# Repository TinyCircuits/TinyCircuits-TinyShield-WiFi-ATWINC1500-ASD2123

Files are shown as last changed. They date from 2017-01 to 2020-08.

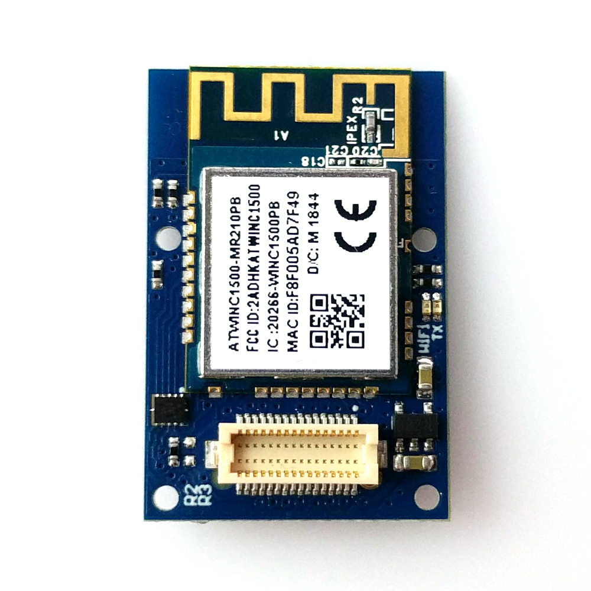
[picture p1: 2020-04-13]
images/ASD2123-R-Tutorial-Image-01.jpg

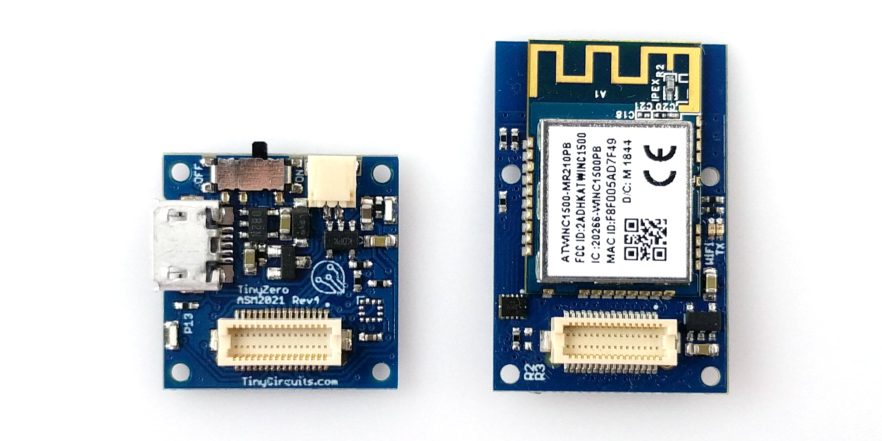
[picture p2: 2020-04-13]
images/ASD2123-R-Tutorial-Image-02.jpg

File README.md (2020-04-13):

# TinyCircuits TinyShield WiFi ATWINC1500 Board
# ASD2123 Rev1

These are the design files for the TinyCircuits ASD2123 Rev 1 PCB.  This is a TinyShield board that has a Atmel ATWINC1500 WiFi module, local power supply and level shifters to connect between the TinyDuino and the WiFi Module. 

Format is in Cadsoft Eagle format - Eagle version 6.2 was used for the original design.

For more infomation on this, check out the product page at TinyCircuits.com:  https://tinycircuits.com/products/wifi-tinyshield-atwinc1500

# License:

Design by TinyCircuits.
All design files are released under the Creative Commons Attribution Share-Alike 3.0 License, see the following link for details: http://creativecommons.org/licenses/by-sa/3.0

All text above must be included in any redistribution or derived design

This project uses designs and concepts developed as part of the Arduino project and the LilyPad project.  The TinyCircuits design files themselves (schematics, PCB and libraries) are not directly derived from these works' design files and have been created new, however the concepts and basic architecture behind the TinyDuino and TinyLily products are derived and we thank the hard work of the organizations below for their contributions to open-source hardware:
  
Original Arduino Uno Design by Team Arduino

LilyPad Arduino Design by Leah Buechley and Sparkfun Electronics

Please support the open-source hardware community

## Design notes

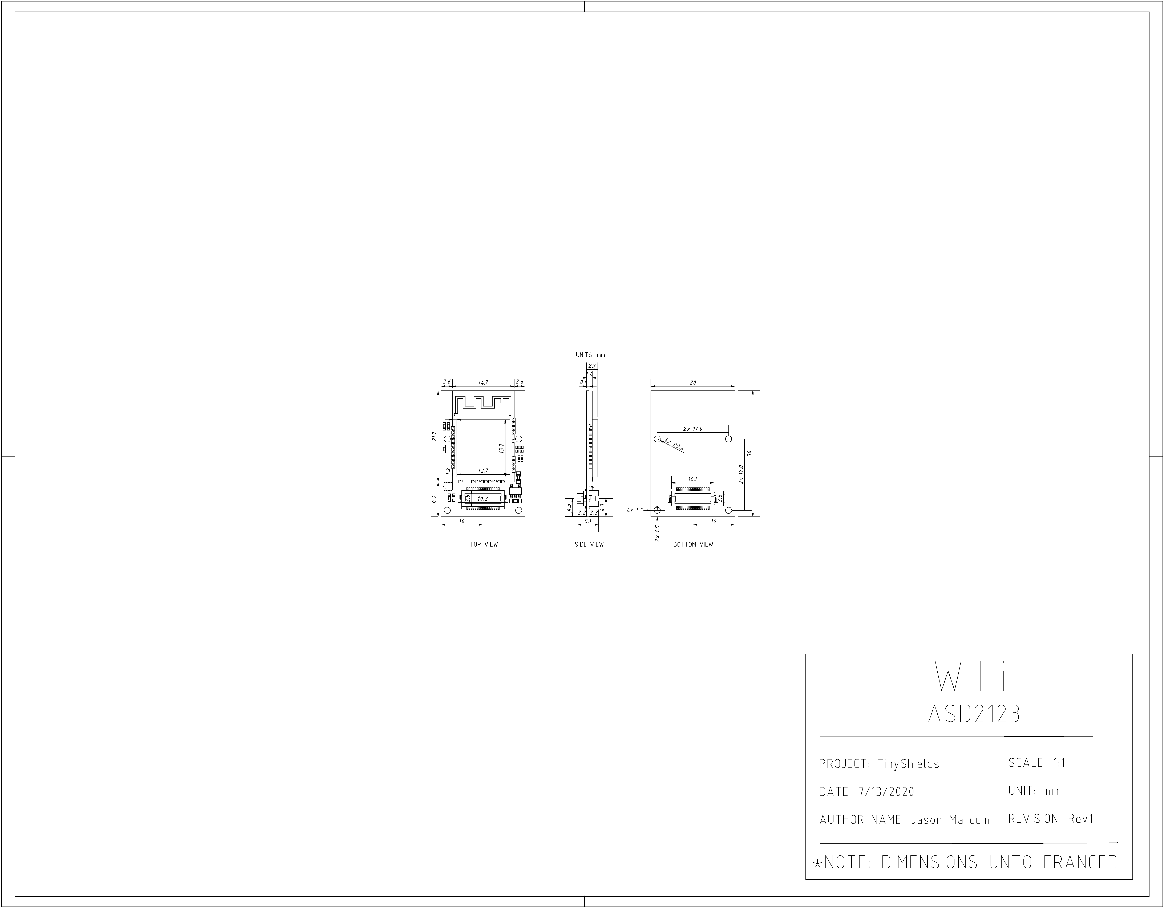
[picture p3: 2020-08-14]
cad/TinyShield_WIFI_ASD2123_REV1-DETAILED_DRAWING-PNG.png

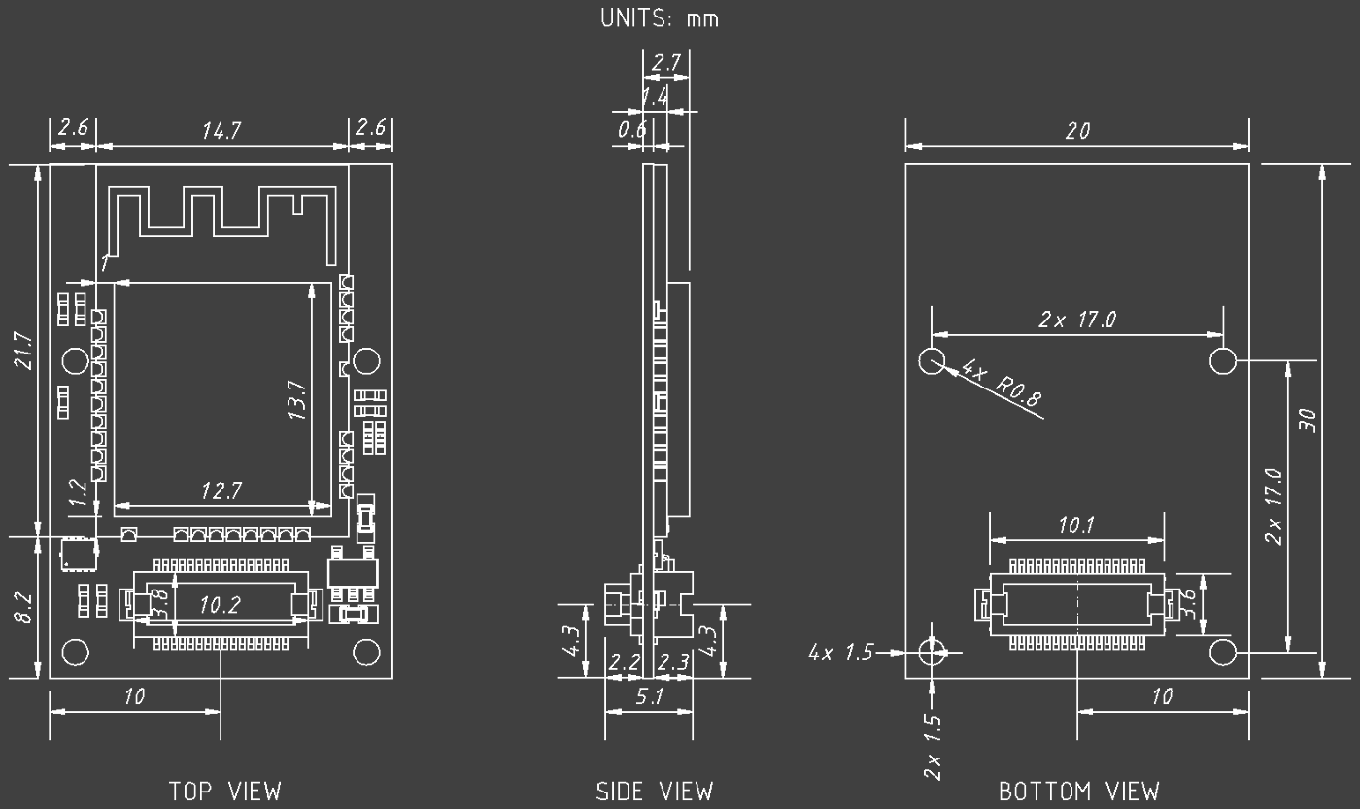
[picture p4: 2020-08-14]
cad/TinyShield_WIFI_ASD2123_REV1-DETAILED_DRAWING_COMPACT-PNG.png

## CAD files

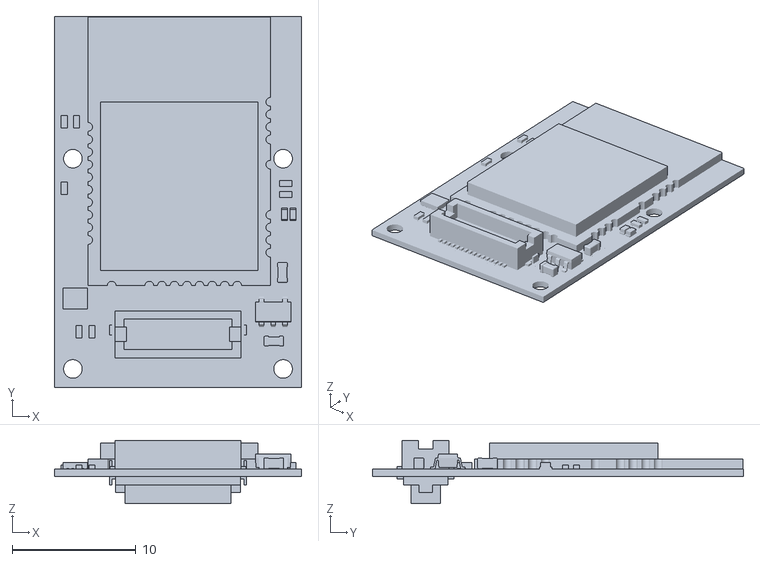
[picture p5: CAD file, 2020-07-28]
cad/TinyShield_WIFI_ASD2123_REV1-STL.stl
20.0 x 30.0 x 5.10

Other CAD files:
cad/TinyShield_WIFI_ASD2123_REV1-DETAILED_DRAWING-DXF.dxf

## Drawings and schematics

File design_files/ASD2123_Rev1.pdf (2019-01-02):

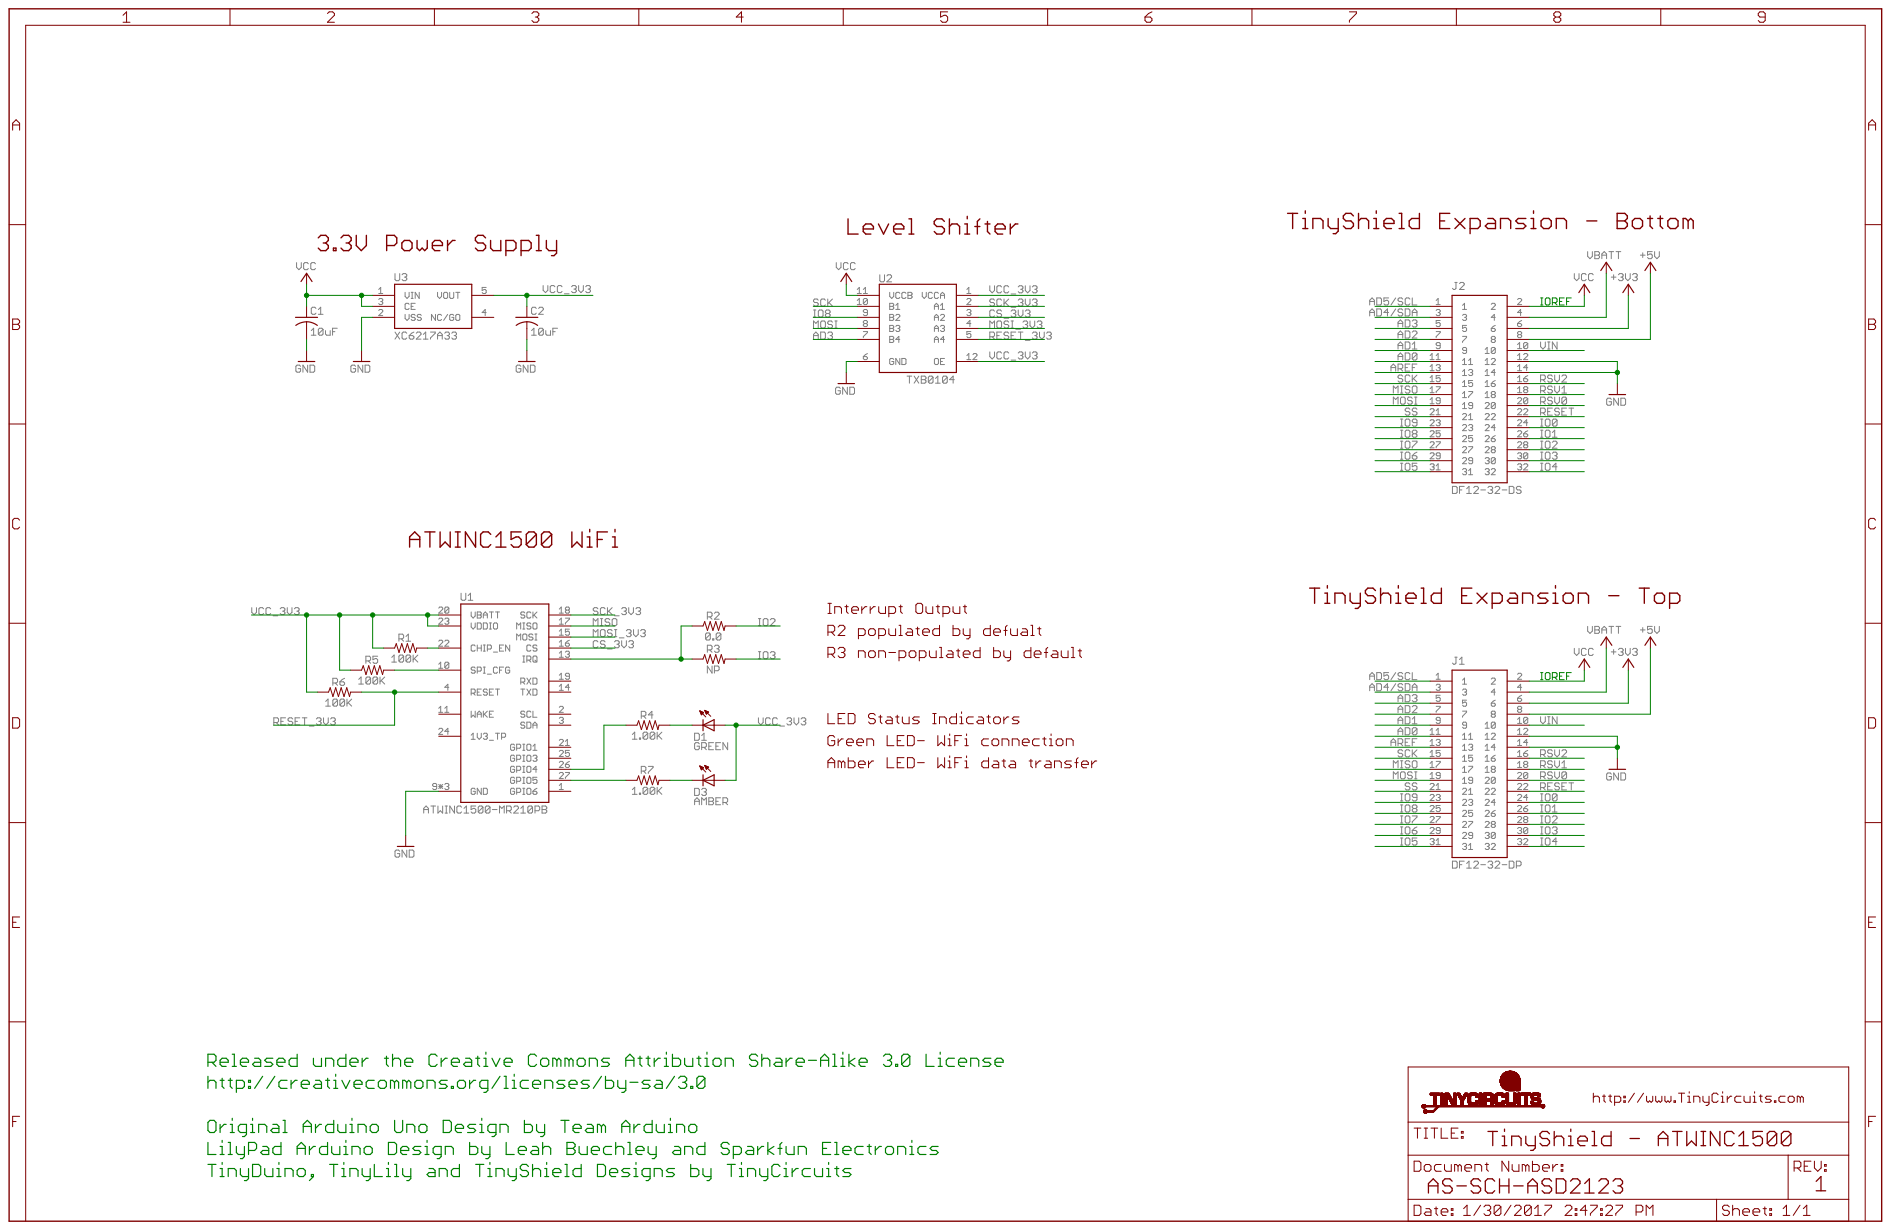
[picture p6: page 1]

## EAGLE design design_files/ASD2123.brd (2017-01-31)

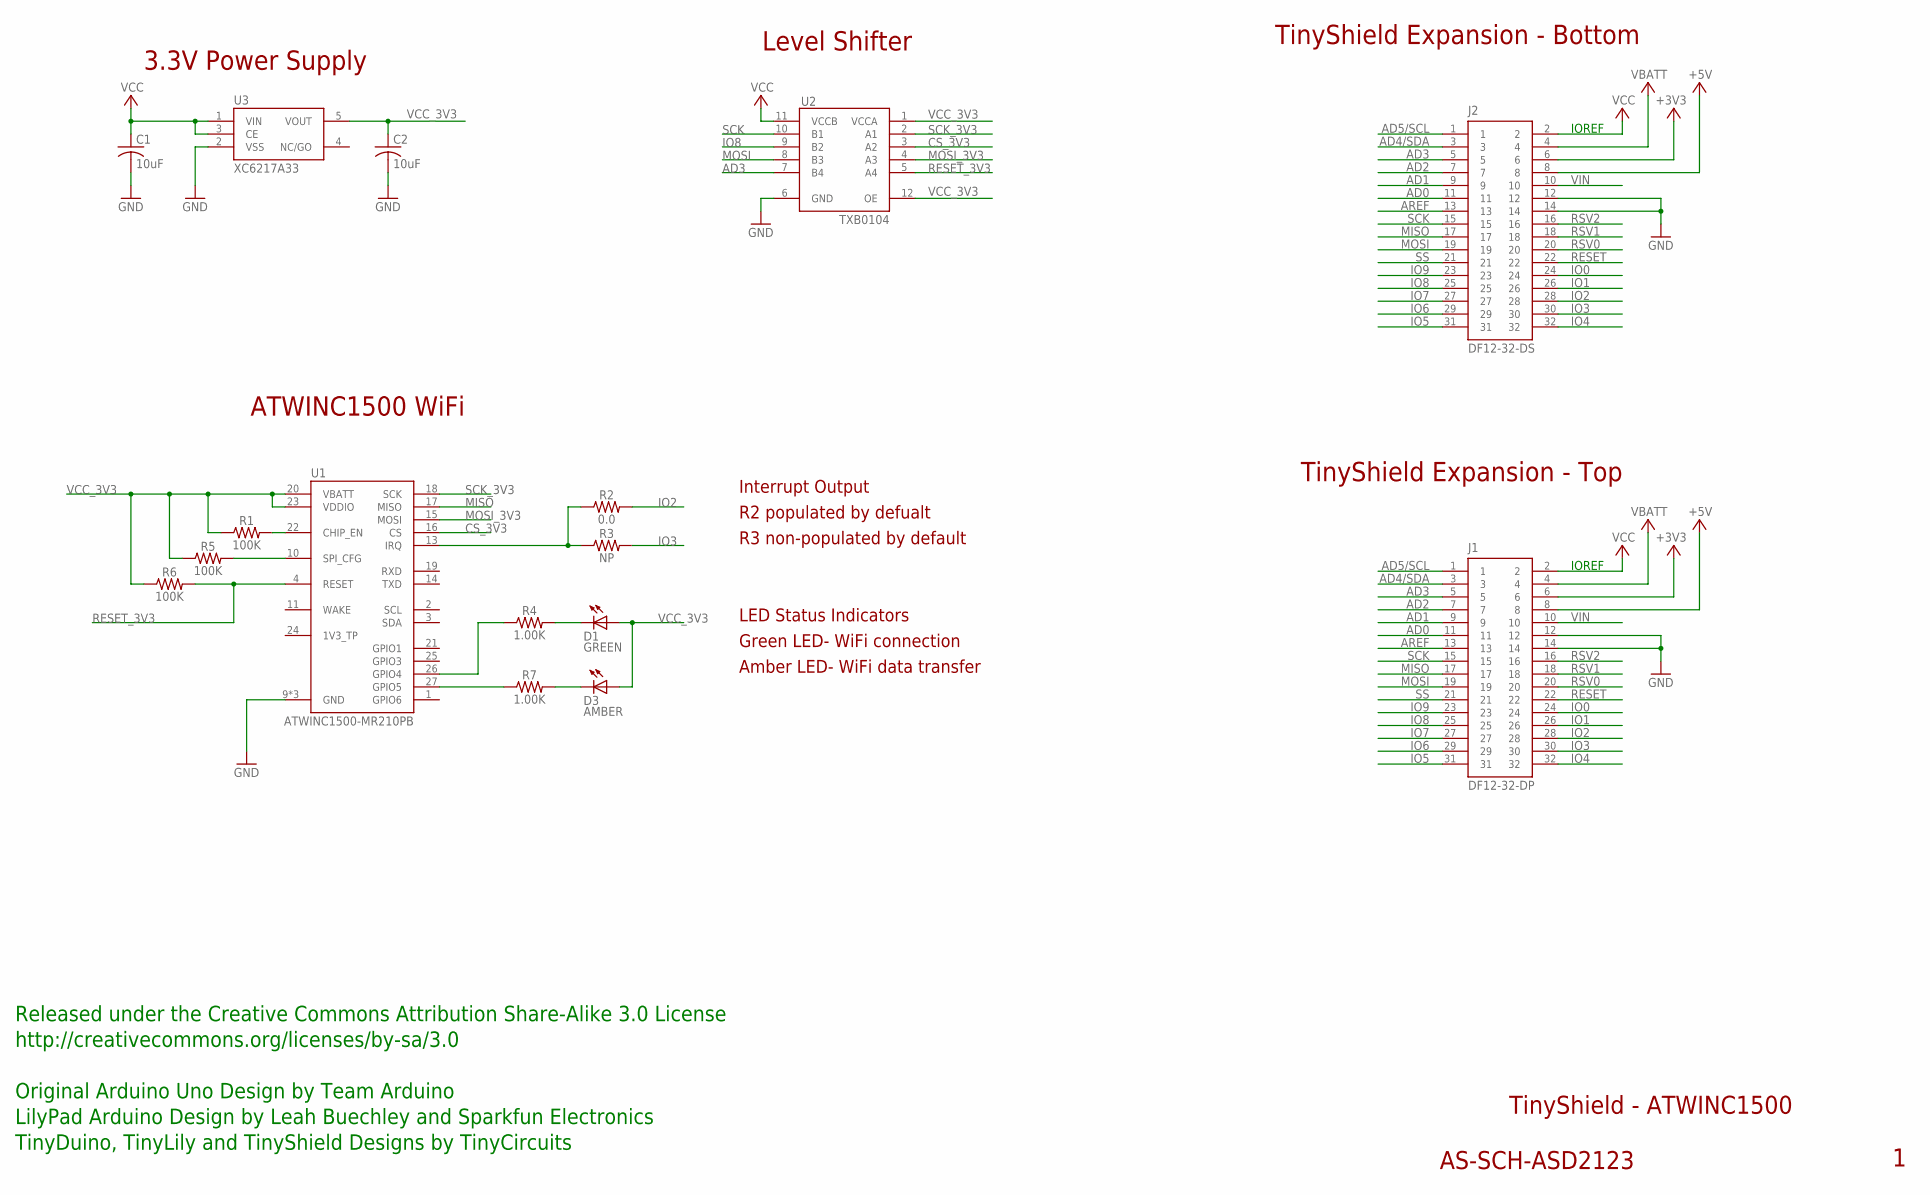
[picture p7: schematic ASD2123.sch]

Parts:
C1, C2: 10uF; C0603; PARTNO AS-ITM-00002
D1: GREEN; 0402_LED
D3: AMBER; 0402_LED
J1: DF12-32-DP; PARTNO AS-ITM-00015
J2: DF12-32-DS; PARTNO AS-ITM-00012
R1, R5, R6: 100K; 0402
R2: 0.0; 0402; PARTNO AS-ITM-00076
R3: NP; 0402; PARTNO AS-ITM-00076
R4, R7: 1.00K; 0402
U1: ATWINC1500-MR210PB
U2: TXB0104; UQFN-12
U3: XC6217A33; SOT-25; PARTNO AS-ITM-00046

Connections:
+3V3: J1.6, J2.6
+5V: J1.8, J2.8
AD0: J1.11, J2.11
AD1: J1.9, J2.9
AD2: J1.7, J2.7
AD3: J1.5, J2.5, U2.7 (B4)
AD4/SDA: J1.3, J2.3
AD5/SCL: J1.1, J2.1
AREF: J1.13, J2.13
CS_3V3: U1.16 (CS), U2.3 (A2)
GND: C1.2, C2.2, J1.12, J1.14, J2.12, J2.14, U1.9 (GND), U1.12 (GND), U1.28 (GND), U2.6 (GND), U3.2 (VSS)
IO0: J1.24, J2.24
IO1: J1.26, J2.26
IO2: J1.28, J2.28, R2.2
IO3: J1.30, J2.30, R3.2
IO4: J1.32, J2.32
IO5: J1.31, J2.31
IO6: J1.29, J2.29
IO7: J1.27, J2.27
IO8: J1.25, J2.25, U2.9 (B2)
IO9: J1.23, J2.23
IRQ: R2.1, R3.1, U1.13 (IRQ)
MISO: J1.17, J2.17, U1.17 (MISO)
MOSI: J1.19, J2.19, U2.8 (B3)
MOSI_3V3: U1.15 (MOSI), U2.4 (A3)
unnamed: R1.2, U1.22 (CHIP_EN)
unnamed: R4.1, U1.26 (GPIO4)
unnamed: R7.1, U1.27 (GPIO5)
unnamed: R5.2, U1.10 (SPI_CFG)
unnamed: D1.2 (C), R4.2
unnamed: D3.2 (C), R7.2
RESET: J1.22, J2.22
RESET_3V3: R6.2, U1.4 (RESET), U2.5 (A4)
RSV0: J1.20, J2.20
RSV1: J1.18, J2.18
RSV2: J1.16, J2.16
SCK: J1.15, J2.15, U2.10 (B1)
SCK_3V3: U1.18 (SCK), U2.2 (A1)
SS: J1.21, J2.21
VBATT: J1.4, J2.4
VCC: C1.1, J1.2, J2.2, U2.11 (VCCB), U3.1 (VIN), U3.3 (CE)
VCC_3V3: C2.1, D1.1 (A), D3.1 (A), R1.1, R5.1, R6.1, U1.20 (VBATT), U1.23 (VDDIO), U2.1 (VCCA), U2.12 (OE), U3.5 (VOUT)
VIN: J1.10, J2.10

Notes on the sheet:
TinyShield Expansion - Bottom
TinyShield - ATWINC1500
AS-SCH-ASD2123
TinyShield Expansion - Top
IOREF
Released under the Creative Commons Attribution Share-Alike 3.0 License
http://creativecommons.org/licenses/by-sa/3.0
LilyPad Arduino Design by Leah Buechley and Sparkfun Electronics
TinyDuino, TinyLily and TinyShield Designs by TinyCircuits
Original Arduino Uno Design by Team Arduino
3.3V Power Supply
ATWINC1500 WiFi
Level Shifter
Interrupt Output
R2 populated by defualt
R3 non-populated by default
LED Status Indicators
Green LED- WiFi connection
Amber LED- WiFi data transfer

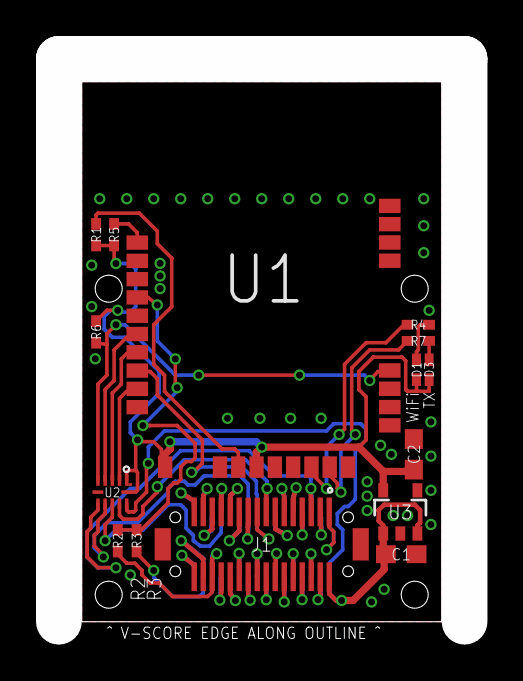
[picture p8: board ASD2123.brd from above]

Board: 2 copper layers, 20.0 x 30.0 mm, 17 parts (1 on the bottom side), 43 nets.

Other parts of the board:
U$1: DOCFIELD-TINYCIRCUITS-PCB

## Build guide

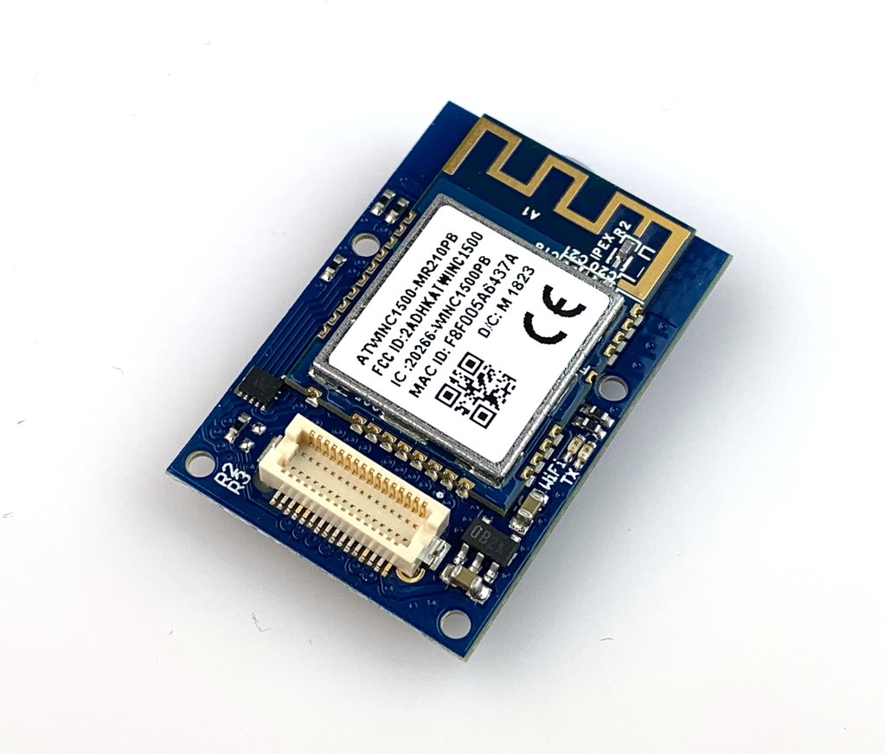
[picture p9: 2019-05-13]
images/ASD2123-R-Tutorial-Image-00.jpg

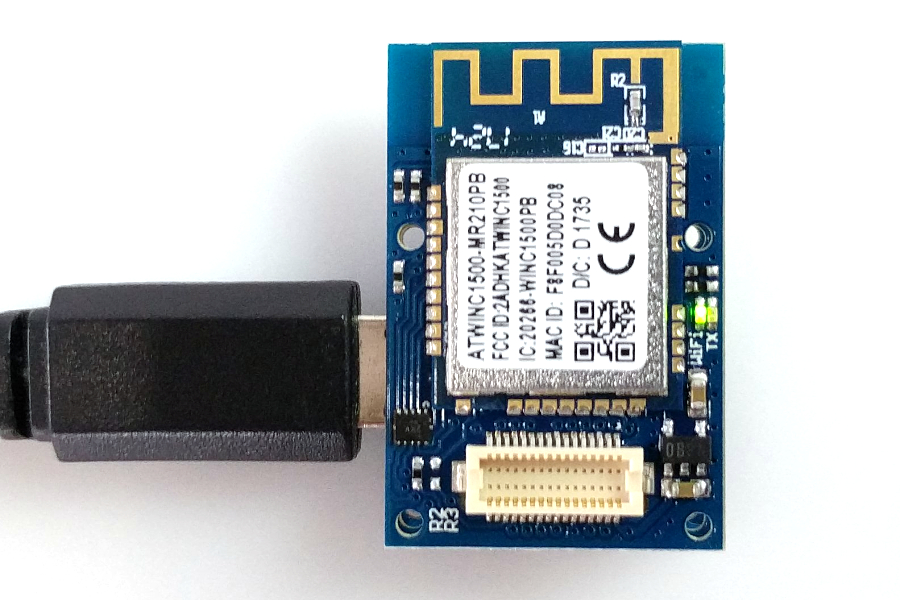
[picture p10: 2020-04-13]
images/ASD2123-R-Tutorial-Animation-01.jpg

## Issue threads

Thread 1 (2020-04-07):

Waiting for WiFi connect does not delay due to missing braces.

AlanKilian, 2020-04-07:
Missing braces for control structure.

  while (WiFi.status() != WL_CONNECTED)
    Serial.print(".");
    delay(500);

should be:
  while (WiFi.status() != WL_CONNECTED) {
    Serial.print(".");
    delay(500);
  }

Using whatever your braces standards are.

TinyCircuits, 2020-04-13:
Fixed the brackets!

Good catch!

Closed 2020-04-13.

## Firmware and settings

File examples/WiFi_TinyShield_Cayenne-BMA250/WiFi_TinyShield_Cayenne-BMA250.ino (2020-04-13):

/*
  TinyDuino WiFi Tutorial

  BMA250 TinyZero Accelerometer Internet of Things Project: 
  This program uses the TinyZero with an accelerometer populated on it to 
  connect to WiFi for a Cayenne Internet of Things application.

  NOTE: There are a couple things you'll need to change for this to work!

  Written 21 November 2018
  By Laverena Wienclaw
  Modified 21 May 2019

  https://TinyCircuits.com
*/

#include <Wire.h>         // For I2C communication with sensor
#include <WiFi101.h>      // For connecting to WiFi
#include "BMA250.h"       // For interfacing with the accel. sensor
#include <CayenneMQTTWiFi101.h> // Cayenne library to connect to transmit data 

/*********************** EDIT THIS SECTION TO MATCH YOUR INFO *************************/
// WiFi network information
char ssid[] = "TinyCircuits";        //  your network SSID (name)
char wifiPassword[] = "__________";  // your network password

// Cayenne authentication info. This should be obtained from the Cayenne Dashboard.
char username[] = "________________________________________";
char password[] = "________________________________________";
char clientID[] = "________________________________________";
/*************************************************************************************/

// Accelerometer sensor variables for the sensor and its values
BMA250 accel_sensor;
int x, y, z;
double temp;

// Define Serial object based on which TinyCircuits processor board is used.
#if defined(ARDUINO_ARCH_SAMD)
  #define SerialMonitorInterface SerialUSB
#else
  #define SerialMonitorInterface Serial
#endif

void setup() {
  SerialMonitorInterface.begin(9600);
  Wire.begin();
  WiFi.setPins(8, 2, A3, -1); // VERY IMPORTANT FOR TINYCIRCUITS WIFI SHIELD

  while (!SerialMonitorInterface); // ***Will halt program until the Serial Monitor is opened***

  // Connect to WiFi and Cayenne
  connectWifi();
  Cayenne.begin(username, password, clientID);

  // Set up the BMA250 acccelerometer sensor
  SerialMonitorInterface.print("Initializing BMA..."); SerialMonitorInterface.println();
  accel_sensor.begin(BMA250_range_2g, BMA250_update_time_64ms); 
}

void loop() {
  // Take sensor reading and print to Serial Monitor
  accel_sensor.read(); //This function gets new data from the acccelerometer

  // Get the acceleration values from the sensor and store them into global variables
  // (Makes reading the rest of the program easier)
  x = accel_sensor.X;
  y = accel_sensor.Y;
  z = accel_sensor.Z;
  temp = ((accel_sensor.rawTemp * 0.5) + 24.0);

  // Call function to display sensor readings on Serial Monitor
  showSerial();

  // Report sensor reading to Cayenne
  Cayenne.loop();
  delay(2000); // delay before looping again to take new reading
}

// Prints the sensor values to the Serial Monitor (found under 'Tools')
void showSerial() {
  SerialMonitorInterface.print("X = ");
  SerialMonitorInterface.print(x);
  
  SerialMonitorInterface.print("  Y = ");
  SerialMonitorInterface.print(y);
  
  SerialMonitorInterface.print("  Z = ");
  SerialMonitorInterface.print(z);
  
  SerialMonitorInterface.print("  Temperature(C) = ");
  SerialMonitorInterface.println(temp);
}

// This function goes through the steps to connect to WiFi using the WiFi101 library
void connectWifi(void){
  // Connect to Wifi network:
  SerialMonitorInterface.print("Connecting Wifi: ");
  SerialMonitorInterface.println(ssid);
  WiFi.begin(ssid, wifiPassword);

  // Loop until connection is secured
  while (WiFi.status() != WL_CONNECTED){
    SerialMonitorInterface.print(".");
    delay(500);
  }

  // Success message and put WiFi in low power mode to save energy
  WiFi.maxLowPowerMode();
  SerialMonitorInterface.println("");
  SerialMonitorInterface.println("WiFi connected");
}

// Default function for sending sensor data at intervals to Cayenne.
CAYENNE_OUT_DEFAULT()
{
  // Write data to Cayenne here:
  Cayenne.virtualWrite(1, x);
  Cayenne.virtualWrite(2, y);
  Cayenne.virtualWrite(3, z);
  Cayenne.virtualWrite(4, temp);
}

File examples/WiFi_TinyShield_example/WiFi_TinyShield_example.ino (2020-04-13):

/*
  TinyDuino WiFi TinyShield Example Sketch

  Just a basic tutorial showing you how to connect to WiFi with the Wifi
  TinyShield

  NOTE: There are a couple things you'll need to change for this to work!

  Written 29 May 2018
  By Laverena Wienclaw
  Modified 07 January 2019
  By Hunter Hykes

  https://TinyCircuits.com
*/

// This library is for the wifi connection
#include <WiFi101.h>

/*********************** EDIT THIS SECTION TO MATCH YOUR INFO *************************/
char ssid[] = "TinyCircuits";  //  your network SSID (name)
char wifiPassword[] = "********";  // your network password

// Define Serial object based on which TinyCircuits processor board is used.
#if defined(ARDUINO_ARCH_SAMD)
  #define SerialMonitorInterface SerialUSB
#else
  #define SerialMonitorInterface Serial
#endif

void setup() {
  SerialMonitorInterface.begin(9600);
  WiFi.setPins(8, 2, A3, -1); // VERY IMPORTANT FOR TINYDUINO
  while(!SerialMonitorInterface);

  // Attempt to connect to Wifi network:
  SerialMonitorInterface.print("Connecting Wifi: ");
  SerialMonitorInterface.println(ssid);

  // Connect to WiFi, and loop until connection is secured
  WiFi.begin(ssid, wifiPassword);
  while (WiFi.status() != WL_CONNECTED){
    SerialMonitorInterface.print(".");
    delay(500);
  }
    

  // Print out the local IP address
  SerialMonitorInterface.println("");
  SerialMonitorInterface.println("WiFi connected");
  SerialMonitorInterface.println("IP address: ");
  IPAddress ip = WiFi.localIP();
  SerialMonitorInterface.println(ip);
}

void loop()
{
  SerialMonitorInterface.print("Main loop entered. Now that we're connected, let's do something cool.");
  delay(60000); // Wait a minute before going back through main loop
}

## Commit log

2019-01-02 update format
    [ASD2123.brd, ASD2123.sch]
2020-04-13 fix brackets
2020-07-28 Add CAD data
    [TinyShield_WIFI_ASD2123_REV1-DETAILED_DRAWING-DXF.dxf, TinyShield_WIFI_ASD2123_REV1-STL.stl]
2020-08-14 Update CAD drawing
    [TinyShield_WIFI_ASD2123_REV1-DETAILED_DRAWING-DXF.dxf]
